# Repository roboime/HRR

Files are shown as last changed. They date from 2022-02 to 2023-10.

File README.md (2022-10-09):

uint8_t uartBuf[64];
	uint8_t paramArray[2];  // contem os parametros de setar id
	uint8_t paramArray2[5];  // parametros da primeira posiçao
	uint8_t paramArray3[5];  // parametros da segunda posiçao
	uint8_t motorId;

  void sendInstruction(uint8_t instruction, uint8_t* paramArray, uint8_t numParams){
	  //while(huartptr->gState != HAL_UART_STATE_READY);	//Tem que implementar timeout
	  uartBuf[0] = 0xFF;				//Header
	  uartBuf[1] = 0xFF;				//Header
	  uartBuf[2] = motorId;				//ID
	  uartBuf[3] = numParams + 2;		//Length
	  uartBuf[4] = instruction;			//Instruction
	  uint8_t i;
	  uint8_t somaParams = 0;
	  for(i=0; i<numParams; i++){
		  uartBuf[i+5] = paramArray[i];	//Parameters
		  somaParams += paramArray[i];
	  }
	  uartBuf[i+5] = ~(motorId + numParams + 2 + instruction + somaParams);	//Checksum
	  HAL_UART_Transmit_DMA(&huart1, uartBuf, numParams + 6);  //tem q ficar mudando a porta aqui
}

	void main(){

	uint8_t novoId = 0x00;
  	  paramArray[0] = 0x03; 	//Starting adress da instruçao de ID
  	  paramArray[1] = novoId; 	//novo ID (se mudar tem q mudar o uartbuf2 do sendInstruction)
  	  motorId = 0xFE;  // ID de broadcast
  	  uint16_t pos1 = 1000;
  	  uint16_t pos2 = 500;
  	  uint16_t spd = 500;

  	  sendInstruction(0x03, paramArray, 2);  // set ID

  	  motorId = novoId;

  	  paramArray2[0] = 30;			//Goal position
  	  paramArray2[1] = pos1;		//Conferir endianess
  	  paramArray2[2] = pos1>>8;
  	  paramArray2[3] = spd;
  	  paramArray2[4] = spd>>8;

  	  paramArray3[0] = 30;			//Goal position
  	  paramArray3[1] = pos2;		//Conferir endianess
  	  paramArray3[2] = pos2>>8;
  	  paramArray3[3] = spd;
  	  paramArray3[4] = spd>>8;

}

  while (1)
  {
	  sendInstruction(0x03, paramArray2, 5);
	  HAL_Delay(2000);
	  sendInstruction(0x03, paramArray3, 5);
	  HAL_Delay(2000);
}

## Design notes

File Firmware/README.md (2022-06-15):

# HRR 2022
## Firmware

### Função

Controlar os motores AX-12A e MX-28T das pernas do robô por protocolo UART half duplex e controlar os motores MG90s dos braços por PWM.

### Features a serem implementados

- [x] Colocar código para rodar no STM32
- [x] Controle dos motores das pernas
- [ ] Feedback dos motores das pernas
- [ ] Controle dos motores dos braços
- [x] Leitura do CSV da mecatrônica
- [x] Diferentes tipos de passos
- [x] Comunicação com inteligência
- [ ] Comunicação RF para telemetria
- [ ] Interface gráfica no computador para telemetria
- [ ] Acelerômetro para detecção e tratamento de quedas
- [x] Medição de carga da bateria e desligamento em carga baixa
- [ ] Gravação de log no cartão de memória

### Periféricos e pinos

| Periférico | Pino MCU  | Função |
| --- | --- | --- |
| TIM3 CHANNEL 1 | PB4 | PWM servo do braço |
| TIM3 CHANNEL 2 | PC7 | PWM servo do braço |
| TIM3 CHANNEL 3 | PB0 | PWM servo do braço |
| TIM3 CHANNEL 4 | PB1 | PWM servo do braço |
| TIM4 CHANNEL 3 | PB8 | PWM servo do braço |
| TIM4 CHANNEL 4 | PB9 | PWM servo do braço |
| TIM6 | | Interrupção de controle |
| ADC1 IN1 | PA1 | Medidor de carga da bateria |
| SDIO D0 | PC8 | Cartão de memória |
| SDIO CK | PC12 | Cartão de memória |
| SDIO CMD | PD2 | Cartão de memória |
| SDIO DETECT | PC9 | Cartão de memória |
| UART4 TX | PC10 | Comunicação com Raspberry Pi  |
| UART4 RX | PC11 | Comunicação com Raspberry Pi  |
| USART1 | PB6 | Servos da perna |
| USART2 | PA2 | Servos da perna |
| USART3 | PD8 | Servos da perna |
| USART6 | PC6 | Servos da perna |

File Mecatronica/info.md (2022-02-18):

# Information file

## AX12 relevant information
https://emanual.robotis.com/docs/en/dxl/ax/ax-12a/#goal-position

- Stall Torque	1.5 [N.m] (at 12 [V], 1.5 [A])
- Stable motions are possible with robots designed for loads with 1/5 or less of the stall torque.
max torque is 0.3 [N.m]
- the data the motor recieves is:
- - Goal Position
0 - 1023 -> 0.29 degreas
- - Moving Speed
0 - 1023 -> 0.111 rpm

## MX28 
max torque 0.62 [N.m]

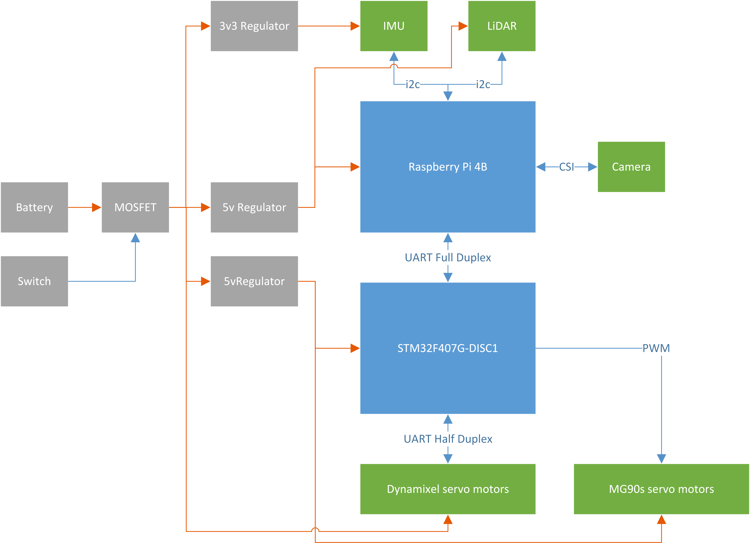
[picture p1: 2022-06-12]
Firmware/Documentation/Hardware block diagram.png

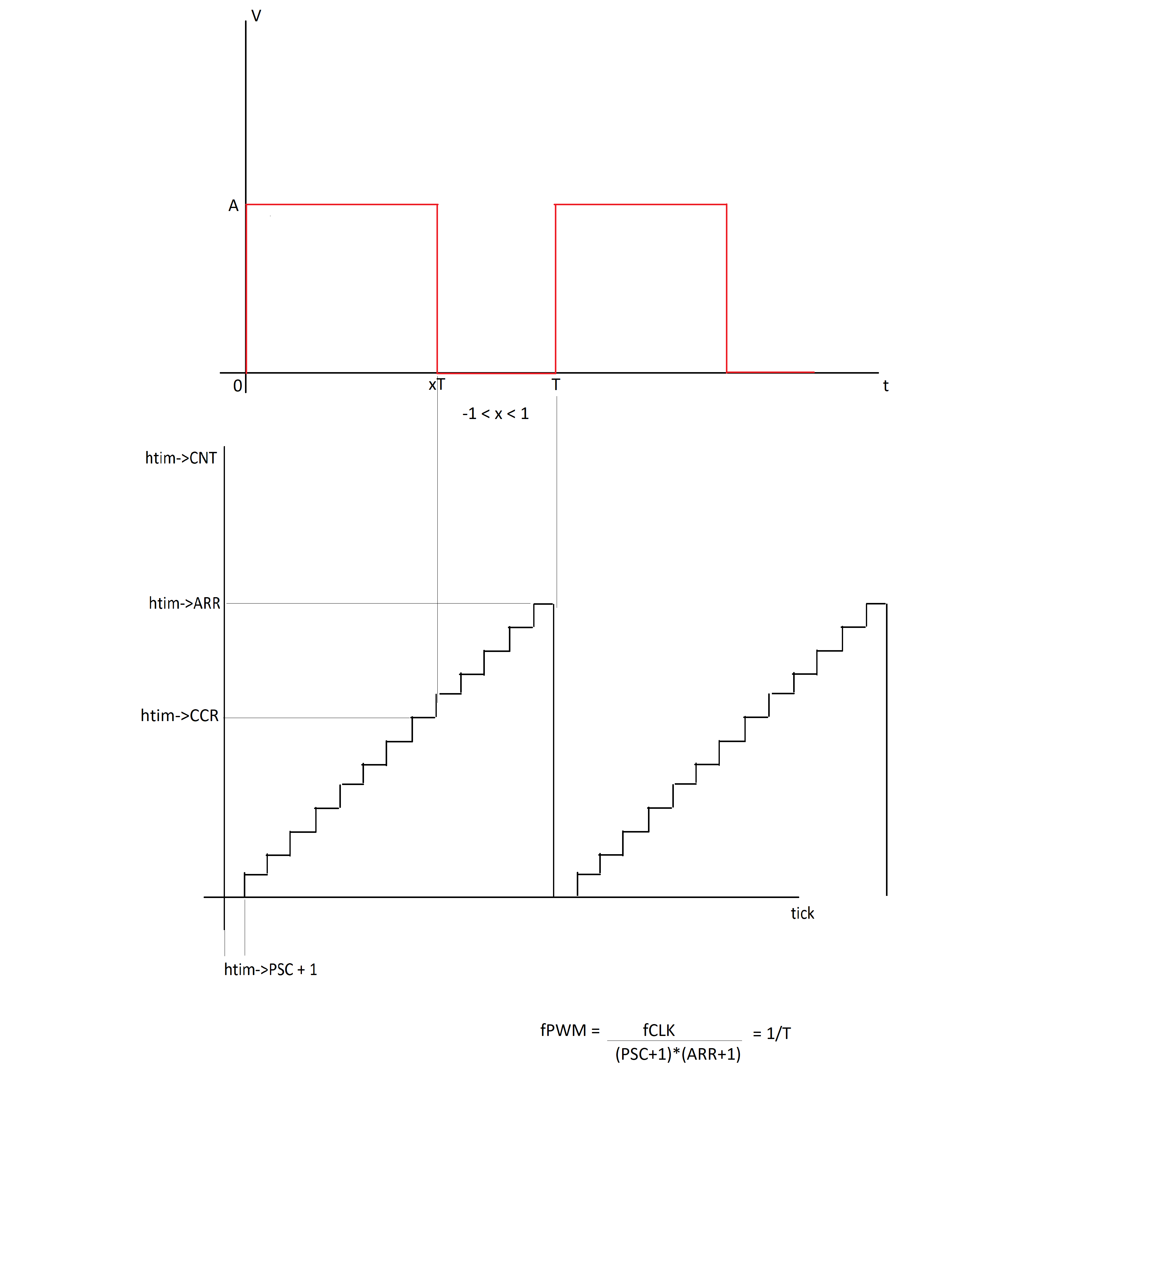
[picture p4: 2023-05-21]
Firmware/PWM com STM32.png

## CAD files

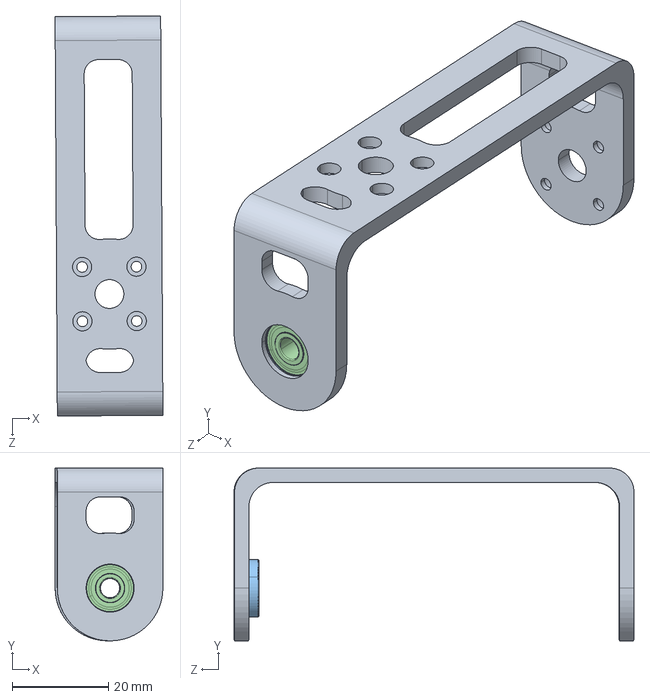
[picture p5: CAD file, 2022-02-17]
Mecatronica/STEP_Files/Prna1_Valor predeterminado_sldprt.STEP
22.5 x 36.0 x 83.3 mm

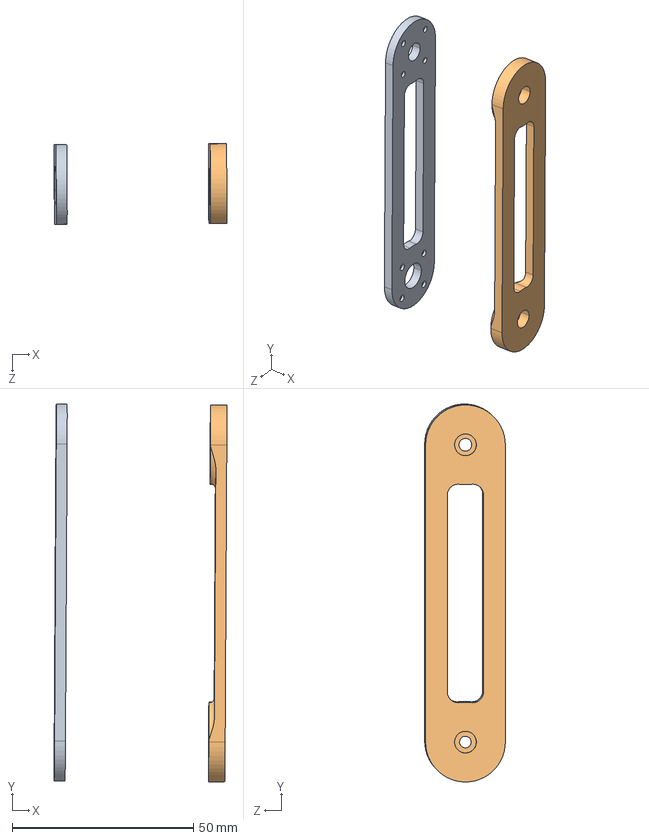
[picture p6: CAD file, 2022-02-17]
Mecatronica/STEP_Files/Perna3_Valor predeterminado_sldprt.STEP
47.7 x 104.3 x 22.3 mm

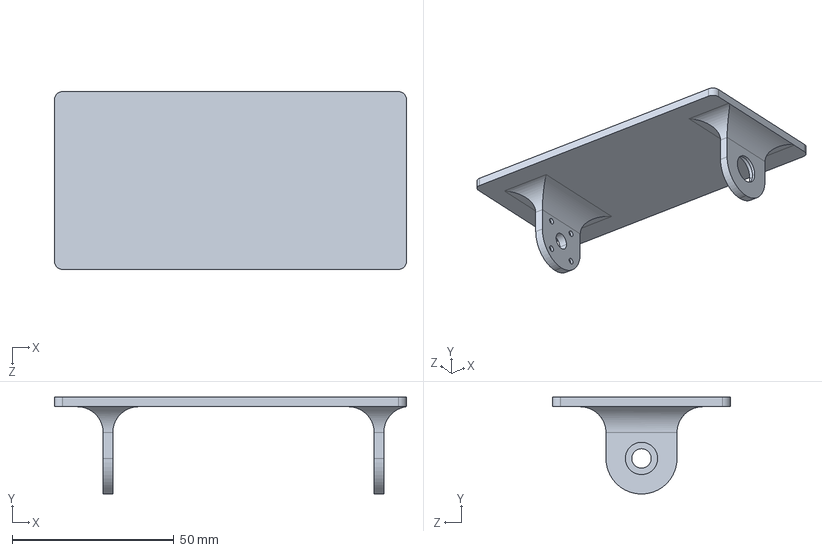
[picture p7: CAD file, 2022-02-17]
Mecatronica/STEP_Files/peça nova perna 1 - Copia_Default_sldprt.STEP
108.9 x 30.0 x 55.0 mm

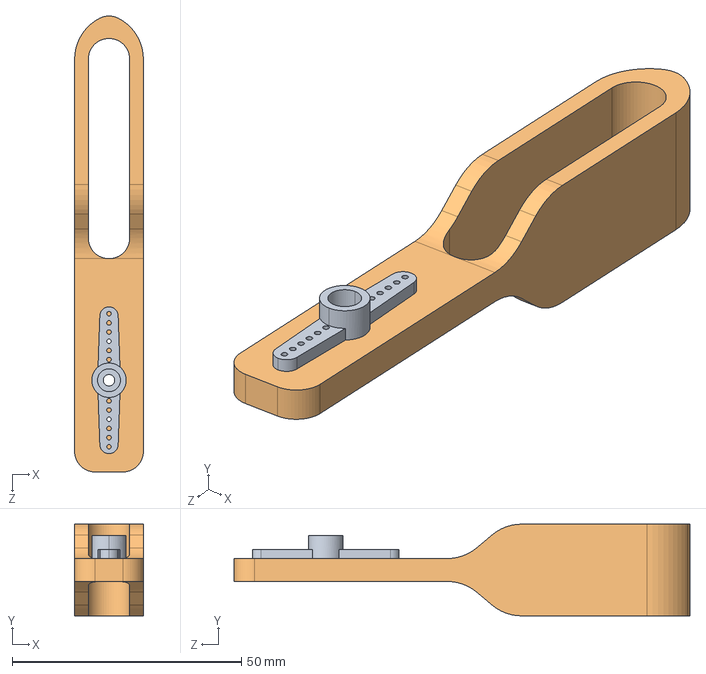
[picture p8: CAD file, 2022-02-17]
Mecatronica/STEP_Files/Braço2_Valor predeterminado_sldprt.STEP
15.0 x 20.0 x 99.4 mm

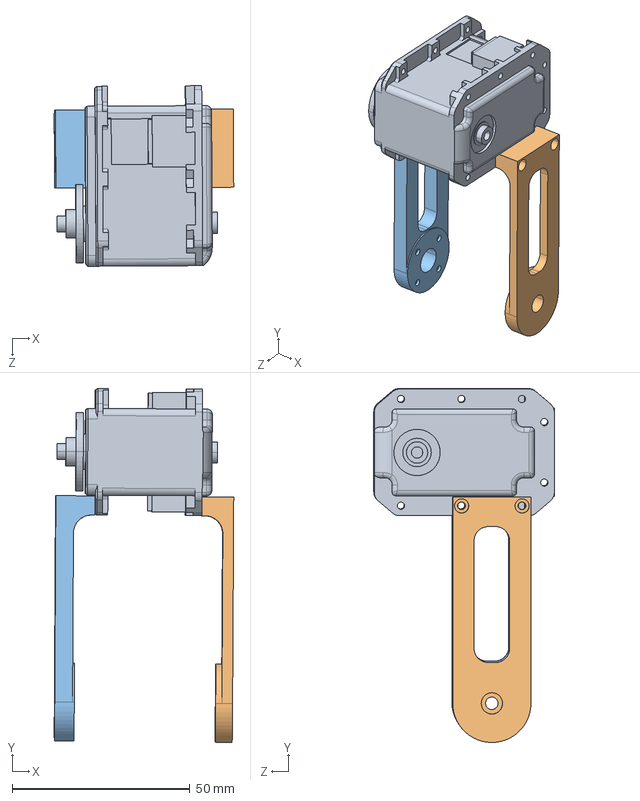
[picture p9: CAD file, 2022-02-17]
Mecatronica/STEP_Files/Perna4_Valor predeterminado_sldprt.STEP
50.5 x 99.5 x 50.8 mm

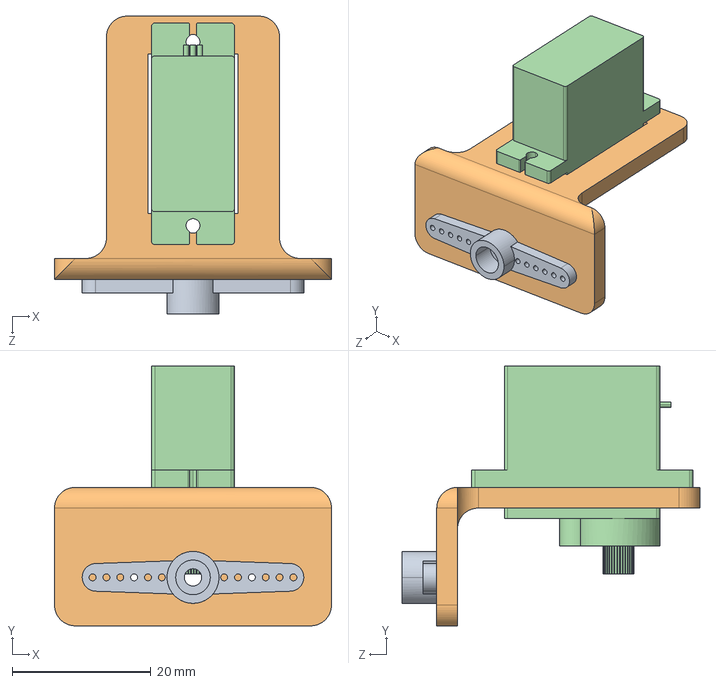
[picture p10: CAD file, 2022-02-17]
Mecatronica/STEP_Files/Braço1_Valor predeterminado_sldprt.STEP
40.0 x 37.5 x 43.0 mm

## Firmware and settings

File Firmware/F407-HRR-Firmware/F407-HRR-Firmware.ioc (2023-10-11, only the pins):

Mcu.UserName=STM32F407VGTx
PA0-WKUP.GPIO_Label=B1 [Blue PushButton]
PA0-WKUP.Signal=GPXTI0
PA1.GPIO_Label=BAT_Voltage
PA1.Signal=SharedAnalog_PA1
PA10.GPIO_Label=OTG_FS_ID
PA10.Signal=USB_OTG_FS_ID
PA11.GPIO_Label=OTG_FS_DM
PA11.Signal=USB_OTG_FS_DM
PA12.GPIO_Label=OTG_FS_DP
PA12.Signal=USB_OTG_FS_DP
PA13.GPIO_Label=SWDIO
PA13.Signal=SYS_JTMS-SWDIO
PA14.GPIO_Label=SWCLK
PA14.Signal=SYS_JTCK-SWCLK
PA2.Signal=USART2_TX
PA5.GPIO_Label=SPI1_SCK [LIS302DL_SCL/SPC]
PA5.Signal=SPI1_SCK
PA6.GPIO_Label=SPI1_MISO [LIS302DL_SDO]
PA6.Signal=SPI1_MISO
PA7.GPIO_Label=SPI1_MOSI [LIS302DL_SDA/SDI/SDO]
PA7.Signal=SPI1_MOSI
PA9.GPIO_Label=VBUS_FS
PA9.Signal=USB_OTG_FS_VBUS
PB0.Signal=S_TIM3_CH3
PB1.Signal=S_TIM3_CH4
PB10.GPIO_Label=CLK_IN [MP45DT02_CLK]
PB10.Signal=I2S2_CK
PB13.Signal=SPI2_SCK
PB15.Signal=SPI2_MOSI
PB3.GPIO_Label=SWO
PB3.Signal=SYS_JTDO-SWO
PB4.Signal=S_TIM3_CH1
PB6.Signal=USART1_TX
PB8.Signal=S_TIM4_CH3
PB9.Signal=S_TIM4_CH4
PC10.Signal=UART4_TX
PC11.Signal=UART4_RX
PC12.Signal=SDIO_CK
PC14-OSC32_IN.GPIO_Label=PC14-OSC32_IN
PC14-OSC32_IN.Signal=RCC_OSC32_IN
PC15-OSC32_OUT.GPIO_Label=PC15-OSC32_OUT
PC15-OSC32_OUT.Signal=RCC_OSC32_OUT
PC2.Signal=SPI2_MISO
PC3.GPIO_Label=PDM_OUT [MP45DT02_DOUT]
PC3.Signal=I2S2_SD
PC6.Signal=USART6_TX
PC7.Signal=S_TIM3_CH2
PC8.Signal=SDIO_D0
PC9.GPIO_Label=SD_Detect
PC9.Signal=GPIO_Input
PD12.GPIO_Label=LD4 [Green Led]
PD12.Signal=GPIO_Output
PD13.GPIO_Label=LD3 [Orange Led]
PD13.Signal=GPIO_Output
PD14.GPIO_Label=LD5 [Red Led]
PD14.Signal=GPIO_Output
PD15.GPIO_Label=LD6 [Blue Led]
PD15.Signal=GPIO_Output
PD2.Signal=SDIO_CMD
PD8.Signal=USART3_TX
PE1.GPIO_Label=MEMS_INT2 [LIS302DL_INT2]
PE1.Signal=GPXTI1
PE2.Signal=GPIO_Output
PH0-OSC_IN.GPIO_Label=PH0-OSC_IN
PH0-OSC_IN.Signal=RCC_OSC_IN
PH1-OSC_OUT.GPIO_Label=PH1-OSC_OUT
PH1-OSC_OUT.Signal=RCC_OSC_OUT

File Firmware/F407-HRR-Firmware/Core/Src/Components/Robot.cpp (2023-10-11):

/*
 * Robot.cpp
 *
 *  Created on: May 16, 2022
 *      Author: Gabriel
 */

#include "Robot.hpp"
#include "Defines.hpp"

#define RL 2200		//R3 da placa
#define RH 10000	//R2 da placa
#define VOLTAGE_CONVERSION (RL+RH)*3.3/(RL*4096)	//VDD = 3.3v em ADC 12 bits
#define VOLTAGE_LOW 0	//Limite inferior da voltagem da bateria

extern UART_HandleTypeDef huart1;
extern UART_HandleTypeDef huart2;
extern UART_HandleTypeDef huart3;
extern UART_HandleTypeDef huart6;
extern ADC_HandleTypeDef hadc1;

Robot::Robot() {
//								Porta	ID	Zero Min Max
        legs[5] = new Dynamixel(&huart1, 0, 357, 0, 1023);	//5 da mecatronica PB6 (ok)
		legs[3] = new Dynamixel(&huart2, 0, 357, 0, 1023);	//3 da mecatronica PA2 (ok)
		legs[4] = new Dynamixel(&huart3, 0, 512, 0, 1023);	//4 da mecatronica PD8 <- n ligou // mudou pra AX(ok)
		legs[2] = new Dynamixel(&huart6, 0, 513, 0, 4095);	//2 da mecatronica PC6 <- mau contato
		legs[6] = new Dynamixel(&huart1, 1, 977, 0, 1023);	//6 da mecatronica PB6 (ok)
		legs[8] = new Dynamixel(&huart2, 1, 667, 0, 1023);	//8 da mecatronica PA2 (ok)
		legs[7] = new Dynamixel(&huart3, 1, 220, 0, 1023);	//7 da mecatronica PD8 // mudou pra AX (ok)
		legs[1] = new Dynamixel(&huart6, 1, 667, 0, 1023);	//1 da mecatronica PC6  <- mau contato (ok)
		legs[10] = new Dynamixel(&huart1, 2, 357, 0, 1023);	//10 da mecatronica PB6 (ok)
		legs[11] = new Dynamixel(&huart2, 2, 667, 256, 1023); //11 da mecatronica PA2 (ok)
		legs[0] = new Dynamixel(&huart3, 2, 513, 256, 1023);	//(ok)0 da mecatronica PD8 // olhando o robô de frente, começa na perna esquerda de baixo pra cima
		legs[9] = new Dynamixel(&huart6, 2, 2048, 0, 4095);	//9 da mecatronica PC6 <- mau contato
	}
//como saber qual pino da placa plugar os motores UART: apenas veja qual tipo de UART está ligado na discovery
// em seguida siga o caminho físico do fio que se parte em outros 3, ache o data desses 3 fios e ligue os motores conforme
// o código que está acima, por exemplo, se vc notou que o PB6(UART 1) está ligado nos outros 3 fios então os fios que seguem
//serão datas com UART 1, dessa maneira, olhe no código quais motores tem huart1, que seriam os 5,6,10 e eles podem ser ligados em
//qualquer ordem.

void Robot::init(){
#ifdef POSTE

#else
#ifdef SETID //se tiver dúvida olhe o comentário do defines
	uint8_t id = 0;
	for(uint32_t i=0; i<2000; i++){
		leds(id);
		if(HAL_GPIO_ReadPin(B1_GPIO_Port, B1_Pin)){
			id = (id+1) % 3;	//São 3 ID possiveis
			i=0;
			HAL_Delay(2);
			while(HAL_GPIO_ReadPin(B1_GPIO_Port, B1_Pin));
		}
		HAL_Delay(1);
	}
	for (int i=2; i<6; i++){
		legs[i]->setId(id);
		//legs[i]->setConfig();  //reseta sempre os motores de id 1
	}
	error((errorTypeDef)15);	//Pisca todos os leds para avisar que gravou
#else
	FRESULT res[numStepTypes];
	for (uint32_t i=0; i<numStepTypes; i++){
		res[i] = f_open(&stepFile[i], stepFilePaths[i].c_str(), FA_OPEN_EXISTING | FA_READ);
		if(res[i]){
			if(res[i] == FR_NOT_READY){
				//Sem SD
				error(ERR_NO_SD);
			}else if(res[i] == FR_NO_FILE || res[i] == FR_NO_PATH){
				//Arquivo não encontrado
				error(ERR_FILE_NOT_FOUND);
			}else{
				error(ERR_MISC);
			}
		}
	}
	leds(status = STATUS_READY);
#endif
#endif
}

void Robot::controlCallback(){
#ifdef POSTE
	if(batteryVoltage() < VOLTAGE_LOW){
		//Rotina para desligar os motores (pode ser no erro também)
		error(ERR_LOW_BATTERY);
	}
	switch(desiredStep){
	case STEP_FORWARD:
		break;
	case STEP_LEFT:
		break;
	case STEP_RIGHT:
		break;
	case STEP_STOP:
		break;
	}
#else
	uint16_t data[numLegMotors][2];
	if(f_eof(&stepFile[currentStep])){
		//EOF
		f_rewind(&stepFile[currentStep]);
		//Só troca de tipo de passo depois de o atual acabar
 		currentStep = nextStep();
	}
	if(batteryVoltage() < VOLTAGE_LOW){
		//Rotina para desligar os motores (pode ser no erro também)
		error(ERR_LOW_BATTERY);
	}
	for(uint32_t i=0; i<numLegMotors; i++){
		if(f_read(&stepFile[currentStep], data[i], 4, nullptr) != FR_OK){
			//SD removido
			error(ERR_NO_SD);
		}
		legs[i]->moveRelative(data[i][0], data[i][1]);
	}
#endif
}

void Robot::setMovement(stepTypeDef step){
	desiredStep = step;
}

void Robot::error(errorTypeDef error){
	status = STATUS_ERROR;
	while (true){
		leds(error);
		HAL_Delay(100);
		leds(0);
		HAL_Delay(100);
	}
}

void Robot::leds(uint8_t binary){
	HAL_GPIO_WritePin(LD3_GPIO_Port, LD3_Pin, (GPIO_PinState)(binary & 1));
	HAL_GPIO_WritePin(LD4_GPIO_Port, LD4_Pin, (GPIO_PinState)((binary>>1) & 1));
	HAL_GPIO_WritePin(LD5_GPIO_Port, LD5_Pin, (GPIO_PinState)((binary>>2) & 1));
	HAL_GPIO_WritePin(LD6_GPIO_Port, LD6_Pin, (GPIO_PinState)((binary>>3) & 1));
}

float Robot::batteryVoltage(){
	float voltage = battInt*VOLTAGE_CONVERSION;	//12 bits
	HAL_ADC_Stop_DMA(&hadc1);
	HAL_ADC_Start_DMA(&hadc1, (uint32_t*)&battInt, 1);
	return voltage;
}

Robot::stepTypeDef Robot::nextStep(){
	switch (currentStep){
	case STEP_FORWARD:
		if(desiredStep == STEP_FORWARD){
			return STEP_FORWARD;
		}else{
			return STEP_LAST;
		}
		break;
	case STEP_LEFT:
		if(desiredStep == STEP_FORWARD){
			return STEP_FIRST;
		}else{
			return desiredStep;
		}
		break;
	case STEP_RIGHT:
		if(desiredStep == STEP_FORWARD){
			return STEP_FIRST;
		}else{
			return desiredStep;
		}
		break;
	case STEP_STOP:
		if(desiredStep == STEP_FORWARD){
			return STEP_FIRST;
		}else{
			return desiredStep;
		}
		break;
	case STEP_FIRST:
		if(desiredStep == STEP_FORWARD){
			return STEP_FORWARD;
		}else{
			return STEP_LAST;
		}
		break;
	case STEP_LAST:
		if(desiredStep == STEP_FORWARD){
			return STEP_FIRST;
		}else{
			return desiredStep;
		}
		break;
	case STEP_CLIMB:
		if(desiredStep == STEP_FORWARD){
			return STEP_FIRST;
		}else{
			return desiredStep;
		}
		break;
	case STEP_DESCENT:
		if(desiredStep == STEP_FORWARD){
			return STEP_FIRST;
		}else{
			return desiredStep;
		}
		break;
	}
	return STEP_STOP;	//Para não dar warning na compilação
}

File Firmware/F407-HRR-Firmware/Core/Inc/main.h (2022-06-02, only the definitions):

#define PC14_OSC32_IN_Pin GPIO_PIN_14
#define PC14_OSC32_IN_GPIO_Port GPIOC
#define PC15_OSC32_OUT_Pin GPIO_PIN_15
#define PC15_OSC32_OUT_GPIO_Port GPIOC
#define PH0_OSC_IN_Pin GPIO_PIN_0
#define PH0_OSC_IN_GPIO_Port GPIOH
#define PH1_OSC_OUT_Pin GPIO_PIN_1
#define PH1_OSC_OUT_GPIO_Port GPIOH
#define PDM_OUT_Pin GPIO_PIN_3
#define PDM_OUT_GPIO_Port GPIOC
#define B1_Pin GPIO_PIN_0
#define B1_GPIO_Port GPIOA
#define BAT_Voltage_Pin GPIO_PIN_1
#define BAT_Voltage_GPIO_Port GPIOA
#define SPI1_SCK_Pin GPIO_PIN_5
#define SPI1_SCK_GPIO_Port GPIOA
#define SPI1_MISO_Pin GPIO_PIN_6
#define SPI1_MISO_GPIO_Port GPIOA
#define SPI1_MOSI_Pin GPIO_PIN_7
#define SPI1_MOSI_GPIO_Port GPIOA
#define CLK_IN_Pin GPIO_PIN_10
#define CLK_IN_GPIO_Port GPIOB
#define LD4_Pin GPIO_PIN_12
#define LD4_GPIO_Port GPIOD
#define LD3_Pin GPIO_PIN_13
#define LD3_GPIO_Port GPIOD
#define LD5_Pin GPIO_PIN_14
#define LD5_GPIO_Port GPIOD
#define LD6_Pin GPIO_PIN_15
#define LD6_GPIO_Port GPIOD
#define SD_Detect_Pin GPIO_PIN_9
#define SD_Detect_GPIO_Port GPIOC
#define VBUS_FS_Pin GPIO_PIN_9
#define VBUS_FS_GPIO_Port GPIOA
#define OTG_FS_ID_Pin GPIO_PIN_10
#define OTG_FS_ID_GPIO_Port GPIOA
#define OTG_FS_DM_Pin GPIO_PIN_11
#define OTG_FS_DM_GPIO_Port GPIOA
#define OTG_FS_DP_Pin GPIO_PIN_12
#define OTG_FS_DP_GPIO_Port GPIOA
#define SWDIO_Pin GPIO_PIN_13
#define SWDIO_GPIO_Port GPIOA
#define SWCLK_Pin GPIO_PIN_14
#define SWCLK_GPIO_Port GPIOA
#define SWO_Pin GPIO_PIN_3
#define SWO_GPIO_Port GPIOB
#define MEMS_INT2_Pin GPIO_PIN_1
#define MEMS_INT2_GPIO_Port GPIOE

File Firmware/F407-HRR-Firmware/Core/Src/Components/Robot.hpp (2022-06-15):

/*
 * Robot.hpp
 *
 *  Created on: May 16, 2022
 *      Author: Gabriel
 */

#ifndef SRC_COMPONENTS_ROBOT_HPP_
#define SRC_COMPONENTS_ROBOT_HPP_

#include "main.h"
#include "Dynamixel.hpp"
#include "PWMServo.hpp"
#include "fatfs.h"
#include <string>


class Robot {
public:
	enum stepTypeDef{
		STEP_FORWARD = 0,
		STEP_LEFT,
		STEP_RIGHT,
		STEP_STOP,
		STEP_FIRST,
		STEP_LAST,
		STEP_CLIMB,
		STEP_DESCENT
	};
	enum errorTypeDef{
		ERR_OK = 0,
		ERR_NO_SD,
		ERR_FILE_NOT_FOUND,
		ERR_LOW_BATTERY,
		ERR_MISC
	};
	enum statusTypeDef{
		STATUS_NOT_INITIALIZED = 0,
		STATUS_READY,
		STATUS_ERROR
	};
	statusTypeDef status = STATUS_NOT_INITIALIZED;
	Robot();
	void init();
	void controlCallback();
	void setMovement(stepTypeDef step);
	void error(errorTypeDef error);
	void leds(uint8_t binary);
	float batteryVoltage();
private:
	static const uint32_t numLegMotors = 12;
	static const uint32_t numArmMotors = 6;
	static const uint32_t controlFreq = 100;
	static const uint32_t numStepTypes = 8;
	const std::string stepFilePaths[numStepTypes] = {
			"0:Steps/forward.bin",
			"0:Steps/left.bin",
			"0:Steps/right.bin",
			"0:Steps/stop.bin",
			"0:Steps/first.bin",
			"0:Steps/last.bin",
			"0:Steps/climb.bin",
			"0:Steps/descent.bin"
	};
	FIL stepFile[numStepTypes];
	Dynamixel* legs[numLegMotors];
	PWMServo* arms[numArmMotors];
	volatile uint32_t battInt = 4095;
	stepTypeDef currentStep = STEP_STOP;	//Começa parado
	stepTypeDef desiredStep = STEP_STOP;
	stepTypeDef nextStep();
};

#endif /* SRC_COMPONENTS_ROBOT_HPP_ */

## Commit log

2022-02-15 adicao de diretorios
2022-02-16 added setup file to simpulation and basig ground surfice with step option
2022-02-16 added step files
    [Braço1_Valor predeterminado_sldprt.STEP, Braço2_Valor predeterminado_sldprt.STEP, Perna3_Valor predeterminado_sldprt.STEP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]
2022-02-16 robot assembled, no joint orientation test
2022-02-16 changed joints to be refrenced for easy change
2022-02-16 added input for the legs
2022-02-16 added input for legs
2022-05-24 Serian debug and error checks
    [SerialDebug.cpp, Start.cpp]
2022-06-03 Troca do arquivo para binário e testes com pull up e pull down
2022-06-03 Passos intermediarios e erro de bateria fraca
2022-06-06 ADC tensão da bateria (falta a constante)
2022-06-06 Conversão de voltagem (falta teste) e verificação (falta desligamento)
2022-06-13 Funcionando transmissão UART (100000bauds)
2022-06-15 Maquina de estados
2022-06-15 Correções da maquina de estados e UART da intel
2022-09-03 Mutirão elo 03/09
    Atualizações no moveAbsolute(), half duplex(que ainda falta terminar o transmit e o receive do DMA UART), adição dos parâmetros de pacote de leitura do motor, que por sinal são tabelados.
2022-09-29 tentativa de implementar feedback, possivelmente com bugs
    [Dynamixel.cpp]
2022-10-01 Configurar o motor ID + teste
    1ª tentativa de configurar o ID do motor + teste pra ver se tá funcionando(ps.:ainda não tá)
2022-10-02 Corrigido um bug de Configurar ID do motor + teste, tive que criar um novo, bug relacionado com a renomeacao da pasta do projeto (???)
    [Dynamixel.cpp, Robot.cpp, Robot.hpp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]
2022-10-05 Erros de compilação set id + teste motor
2022-10-05 Fix ARR and set ID
    [F407-HRR-Firmware.ioc, ID_Set_and_Test.ioc, Robot.cpp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]
2022-10-05 corrigidas algumas ma praticas
    [ID_Set_and_Test.ioc, main.c]
2022-10-09 Att que ainda nao funciona
2022-10-09 correçoes feitas na logica do blue button, que era invertida, firmware funcionando ate agora
2022-10-12 Reset do motor FUNCIONANDO!
    setID parece estar setando o ID sempre para o ID 1?
    [Dynamixel.cpp, F407-HRR-Firmware.ioc, Robot.cpp]
2022-10-17 alterado GPIO Mode de Open Drain pra Push Pull, open drain nao tava permitindo usar varios motores simultaneamente, Push Pull nao permite feedback. Pro feedback funcionar provavelmente precisa mudar 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
2022-10-17 colocados os zeros dos motores
2022-10-19 posições do robô setada e motores com torque funcionando!
2022-10-20 Visualizador de passo e PE2
2022-10-22 Para teste com a Raspberry Pi
    Pequena alteração quase inútil apenas para tirar o comando de forçar movimento inicial. Baud rate da UART4 verificado para comunicação entre a Discovery e a Raspberry Pi.
2023-05-21 PWM com STM32.png
2023-10-08 LARC 2023
    Não sabemos se é o código ou o cartão SD que está dando erro
2023-10-10 LARC 2023
    Funciona o código, porém temos que setar as posições iniciais ainda
2023-10-11 tentando setar os motores
    tentando ler o ARR

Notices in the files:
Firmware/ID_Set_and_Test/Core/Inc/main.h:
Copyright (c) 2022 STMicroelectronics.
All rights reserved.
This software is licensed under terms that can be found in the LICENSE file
